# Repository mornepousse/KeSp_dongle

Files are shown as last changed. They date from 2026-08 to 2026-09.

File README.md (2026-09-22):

# KeSp_dongle

USB receiver dongles for the **Niphargus** wireless split keyboard, and soon
for the **Conchodytes** mouse. Both talk 2.4 GHz over nRF24L01+ and share this
single receiver, which presents itself to the host as a USB HID device.

Each Niphargus half is self-contained — its own ESP32-S3-WROOM-1, nRF24L01+ and
16340 cell — and transmits on its own link. Hence the two radios on the dongle,
one per half. The mouse will join on an additional pipe or in a later revision.

KiCad 10 projects. Ecosystem: [Niphargus](https://github.com/mornepousse/Niphargus) (keyboard),
[Conchodytes](https://github.com/mornepousse/Conchodytes) (mouse),
[KeSp_firmware](https://github.com/mornepousse/KeSp_firmware),
[KeSp_software](https://github.com/mornepousse/KeSp_software).

*[Version française plus bas](#version-française).*

| Top | Bottom |
|---|---|
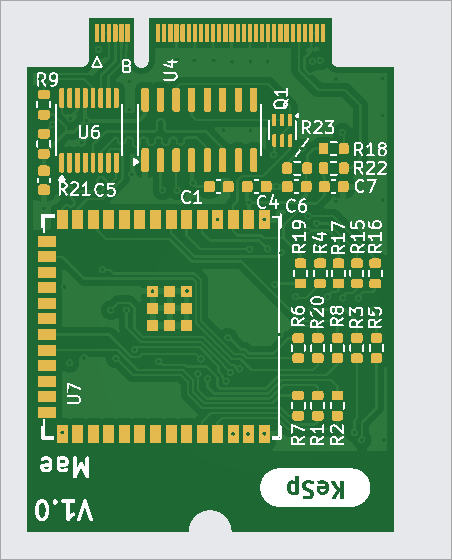
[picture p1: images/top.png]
Board top side
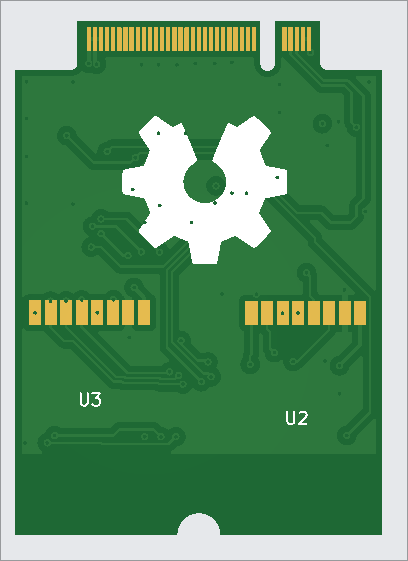
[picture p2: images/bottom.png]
Board bottom side
|  |  |

`dongle-REV1` in revision **V1.0** — the board currently in service.
Top: the CH334R (U6), the CH340C (U4), the ESP32-S3-WROOM-1 (U7) and the M.2
Key B card edge. Bottom: the two NRF24L01+ modules (U2 and U3) on their 2 mm
headers, one per keyboard half.

## The variants

| Folder | MCU | Form factor | Status |
|---|---|---|---|
| `dongle-REV1/` | ESP32-S3-WROOM-1 | M.2 Key B 3042 (30 × 42 mm) | **in service** — V1.0 running in a Dell Latitude 5430's M.2 slot for several months |
| `dongle-REV2/` | ESP32-S3-WROOM-1 | M.2 Key B 3042 (30 × 42 mm) | current design — hub dropped, M.2 CONFIG pins declared, bench supply added; not manufactured yet |
| `dongle-ext/` | ESP32-S3-WROOM-1 | 2.54 mm headers, no M.2 card edge | prototype |

`dongle-REV1` is the only design proven in real use: it enumerates and works as
a USB HID keyboard in the Latitude's M.2 WWAN slot. It does **not** work in a
ThinkPad P16 Gen 1 — the reason, and what REV2 does about it, are written up in
[`docs/hote-thinkpad-p16.md`](docs/hote-thinkpad-p16.md).

## `dongle-REV1` architecture

**Radio** — 2x NRF24L01+ on a shared SPI bus, one per Niphargus half.
Separate CSN/CE/IRQ lines, 100 Ω series resistors on every signal. The
Conchodytes mouse is not wired in yet: it will either share a radio through an
extra receive pipe (the nRF24L01+ handles six) or get its own in a revision.

**USB** — the M.2 slot provides a single USB 2.0 link, split by a hub:

```
M.2 pins 7/9 (D+/D-)
        │
        └─ CH334R (USB 2.0 hub, QSOP-16, crystal-free mode: XI → GND)
             ├── port 1 → ESP32-S3 native USB   (HID in production)
             ├── port 2 → CH340C                (flash and debug without unplugging)
             └── ports 3-4 → unused
```

The CH334R runs natively at 3.3 V with its internal LDO bypassed: **pin 12
(5V) and pin 13 (VDD33) are both tied to 3.3 V**. Leaving pin 12 floating
makes the part overheat and prevents USB enumeration — the classic trap with
this package.

**Power** — no onboard regulator, 3.3 V comes straight from the M.2 slot
(pins 2, 4, 70, 72, 74; grounds on 3, 5, 11, 71, 73).

**M.2 control signals** — `W_DISABLE1#` and `FULL_CARD_POWER_OFF#` get 10 kΩ
pull-ups to 3.3 V, so the host cannot disable the card at boot. `RESET#` is
different: R22 carries it into the ESP32-S3's `EN` node, which also holds a
10 kΩ pull-up (R19) and 100 nF to ground (C7). **The host can therefore reset
the module** — worth remembering when a slot behaves oddly.

| Signal | M.2 pin | Part | Goes to |
|---|---|---|---|
| `W_DISABLE1#` | 8 | R21, 10 kΩ | +3.3 V — pull-up |
| `FULL_CARD_POWER_OFF#` | 6 | R23, 10 kΩ | +3.3 V — pull-up |
| `RESET#` | 67 | R22, 10 kΩ | ESP32-S3 `EN` |

**Auto-reset** — one UMH3N (a dual transistor in SOT-363) driven from the
CH340C DTR/RTS lines to EN and IO0.

## What changed in `dongle-REV2`

REV1 declares nothing on the M.2 CONFIG pins, so a host that reads them before
powering the slot sees "no card present" and never delivers 3.3 V. That is what
happens on a ThinkPad P16 Gen 1. REV2 answers it, and simplifies the USB path
on the way:

| Change | Why |
|---|---|
| `JP2`–`JP5`: CONFIG_0..3 to GND, **open** by default | Lets a code be declared with a solder blob, and swept per host, without a new PCB |
| CH334R hub (`U6`) removed, with `C6` and `J3` | The host now sees a single device whose VID/PID the firmware owns; also retires the CH334R 3.3 V trap |
| ESP32-S3 (`U7:13/14`) straight onto `J2:9/7` | The M.2 USB 2.0 link with nothing in between |
| CH340C (`U4`) moved to `J1` (1 GND, 2 D−, 3 D+, 4 VBUS) | Serial console and auto-reset kept, as a bench programming port |
| `U1` LD1117S33 + `C13`/`C14`, preceded by `D1` (SS14) | Runs the board from the bench cable's VBUS. The series Schottky blocks the slot's 3.3 V from feeding back to the connector through the regulator's internal parasitic path |
| `JP6` between the LDO output and the `+3.3V` rail, **open** by default | Stops the LDO from powering the laptop's WWAN rail when the bench cable is plugged with the card inserted. `C13` stays on the LDO side, so the regulator keeps its output capacitor with the jumper open |

Flashing without unplugging used to go through the CH340C behind the hub. It
now goes through the ESP32-S3's own USB Serial/JTAG over the M.2 link: its
CDC-ACM "supports host controllable chip reset and entry into download mode"
(ESP32-S3 TRM v1.8, p. 1244). Note that the internal USB PHY is **shared**
between USB-OTG and USB Serial/JTAG, one at a time (p. 1244-1245): while the
firmware holds the PHY in OTG for HID, the serial console is gone.

Checked with `kicad-cli` on 2026-09-22: **0 schematic/PCB parity issues, 0
unconnected items**, 41 components on each side.

## Libraries

Custom footprints live in `libs/` and are referenced as
`${KIPRJMOD}/../libs/…` by each project's `fp-lib-table` — no absolute paths,
so the repository clones anywhere.

| Library | Contents |
|---|---|
| `libs/MaeLid.pretty` | NRF24L01, ESP32-S3-DevKitC, JC-ESP32P4-M3, logo |
| `libs/M.2-cards` | M.2 card outline templates |
| `libs/NGFF.pretty` | M.2 / NGFF connectors |

Everything else comes from the standard KiCad libraries and from
`PCM_Espressif` (Plugin and Content Manager, install separately).

## Open items

- `dongle-REV2`: **no clearance exception on `J2`**. 58 of the DRC's 102
  violations are simply adjacent M.2 gold fingers at 0.150 mm against a
  0.200 mm rule. Until an exception is set, the DRC is red by default and
  stops being useful.
- `dongle-REV2`: leftovers to clean — two real clearance violations (`C9` pad
  vs the `/IO0` via at 0.175 mm, GND copper vs `J2:9` at 0.150 mm), a dangling
  via on the VBUS net, a 14 µm dangling track on `/D-_ESP32`, and two
  single-spoke thermal reliefs (`C13`, `J1`).
- `dongle-REV2`: `C8` through `C14` carry `Resistor_SMD:R_1206_3216Metric`.
  Same land pattern, but the BOM and JLCPCB files will describe a resistor
  footprint for 10 µF capacitors. `C14` at 10 µF also sits exactly on the bulk
  capacitance a USB 2.0 device may present on VBUS.
- `dongle-REV2`: `J1` is wired 1 = GND, 2 = D−, 3 = D+, 4 = VBUS, the reverse
  of a USB-A cable's order. The pigtail must be built to match.
- Whether the P16 Gen 1 powers its WWAN slot at all, and on which CONFIG code,
  is still unmeasured. The test costs a wire on an existing V1.0 board — see
  [`docs/hote-thinkpad-p16.md`](docs/hote-thinkpad-p16.md).

## Fabrication

| Folder | Output | Exported |
|---|---|---|
| `dongle-REV1/Gerber/` | gerbers of the manufactured V1.0 batch | 2026-05-27 |
| `dongle-REV1/jlcpcb/` | JLCPCB set — gerbers, BOM, CPL | 2026-08-22 |
| `dongle-REV2/jlcpcb/` | JLCPCB set — gerbers, BOM, CPL | 2026-09-22, after `JP6` |
| `dongle-ext/Gerber/` | gerbers | 2026-06-04 |

REV2's export is in sync with its source, but none of the open items above are
fixed in it — the dangling via and track, the two real clearance violations.
Clean those before ordering.

The REV1 gerbers match the batch that was manufactured, revision V1.0. That
source has since moved on: R9 removed, decoupling completed (C8 through C12),
and the `JP2`–`JP5` CONFIG jumpers added — so `dongle-REV1/` no longer
describes the board sitting in the Latitude.

Neither exported netlists (`*.net`) nor fabrication archives (`*.zip`) are
version-controlled: both regenerate from the source, and importing a stale
netlist overwrites current work.

## Documentation

- [`docs/hote-thinkpad-p16.md`](docs/hote-thinkpad-p16.md) — why the M.2 WWAN
  slot of a ThinkPad P16 Gen 1 never powers the card, the M.2 CONFIG pins, what
  other USB cards in M.2 slots do, the test protocol, and REV2's state.

---

# Version française

Dongles USB récepteurs pour le clavier split sans fil **Niphargus**, et
bientôt pour la souris **Conchodytes**. Les deux émettent en 2,4 GHz via un
nRF24L01+ et partagent ce même récepteur, qui se présente au PC en USB HID.

Chaque moitié du Niphargus est autonome — son ESP32-S3-WROOM-1, son nRF24L01+
et sa cellule 16340 — et émet sur son propre lien. D'où les deux radios du
dongle, une par moitié. La souris arrivera sur un pipe supplémentaire ou dans
une révision ultérieure.

Projets KiCad 10. Écosystème : [Niphargus](https://github.com/mornepousse/Niphargus) (clavier),
[Conchodytes](https://github.com/mornepousse/Conchodytes) (souris),
[KeSp_firmware](https://github.com/mornepousse/KeSp_firmware),
[KeSp_software](https://github.com/mornepousse/KeSp_software).

Les rendus plus haut montrent `dongle-REV1` en révision **V1.0**, la carte
actuellement en service. Dessus : le CH334R (U6), le CH340C (U4),
l'ESP32-S3-WROOM-1 (U7) et le bord de carte M.2 Key B. Dessous : les deux
NRF24L01+ (U2 et U3) sur leurs embases 2 mm, un par moitié de clavier.

## Les variantes

| Dossier | MCU | Format | État |
|---|---|---|---|
| `dongle-REV1/` | ESP32-S3-WROOM-1 | M.2 Key B 3042 (30 × 42 mm) | **en service** — V1.0 montée dans le slot M.2 d'un Dell Latitude 5430 depuis plusieurs mois |
| `dongle-REV2/` | ESP32-S3-WROOM-1 | M.2 Key B 3042 (30 × 42 mm) | conception courante — hub supprimé, pins CONFIG déclarées, alimentation de banc ajoutée ; pas encore fabriquée |
| `dongle-ext/` | ESP32-S3-WROOM-1 | connecteurs 2,54 mm, pas de bord M.2 | prototype |

`dongle-REV1` est la seule éprouvée à l'usage : elle énumère et fonctionne en
clavier USB HID dans le slot M.2 WWAN du Latitude. Elle **ne fonctionne pas**
dans un ThinkPad P16 Gen 1 — la raison, et ce que REV2 y répond, sont
consignées dans [`docs/hote-thinkpad-p16.md`](docs/hote-thinkpad-p16.md).

## Architecture de `dongle-REV1`

**Radio** — 2x NRF24L01+ sur bus SPI partagé, un par moitié de Niphargus.
CSN/CE/IRQ séparés, résistances série de 100 Ω sur chaque signal. La souris
Conchodytes n'est pas encore câblée : elle partagera une radio via un pipe de
réception supplémentaire (le nRF24L01+ en gère six) ou aura la sienne dans une
révision.

**USB** — le slot M.2 fournit un seul lien USB 2.0, dédoublé par un hub :

```
M.2 pins 7/9 (D+/D-)
        │
        └─ CH334R (hub USB 2.0, QSOP-16, mode sans quartz : XI → GND)
             ├── port 1 → USB natif de l'ESP32-S3   (HID en production)
             ├── port 2 → CH340C                    (flash et debug sans démonter)
             └── ports 3-4 → non utilisés
```

Le CH334R tourne en 3,3 V natif, LDO interne bypassé : **pin 12 (5V) et
pin 13 (VDD33) toutes deux au 3,3 V**. Laisser la pin 12 flottante fait
chauffer le composant et empêche l'énumération — c'est le piège de ce boîtier.

**Alimentation** — aucun régulateur embarqué, le 3,3 V vient directement du
slot M.2 (pins 2, 4, 70, 72, 74 ; masses sur 3, 5, 11, 71, 73).

**Signaux M.2** — `W_DISABLE1#` et `FULL_CARD_POWER_OFF#` reçoivent des
pull-ups de 10 kΩ vers 3,3 V, pour que la carte ne soit pas désactivée au
démarrage. `RESET#` est différent : R22 l'amène sur le nœud `EN` de
l'ESP32-S3, qui porte aussi un pull-up de 10 kΩ (R19) et 100 nF vers la masse
(C7). **L'hôte peut donc réinitialiser le module** — bon à savoir quand un slot
se comporte bizarrement.

| Signal | Pin M.2 | Composant | Va vers |
|---|---|---|---|
| `W_DISABLE1#` | 8 | R21, 10 kΩ | +3,3 V — pull-up |
| `FULL_CARD_POWER_OFF#` | 6 | R23, 10 kΩ | +3,3 V — pull-up |
| `RESET#` | 67 | R22, 10 kΩ | `EN` de l'ESP32-S3 |

**Reset automatique** — un UMH3N (double transistor en SOT-363) piloté par les
lignes DTR/RTS du CH340C vers EN et IO0.

## Ce qui change dans `dongle-REV2`

REV1 ne déclare rien sur les pins CONFIG du M.2 : un hôte qui les lit avant
d'alimenter le slot comprend « pas de carte » et ne délivre jamais le 3,3 V.
C'est ce qui se passe sur un ThinkPad P16 Gen 1. REV2 y répond, et simplifie le
chemin USB au passage :

| Modification | Raison |
|---|---|
| `JP2`–`JP5` : CONFIG_0..3 vers GND, **ouverts** par défaut | Permet de déclarer un code à la goutte de soudure, et de les balayer selon l'hôte, sans refaire un PCB |
| Hub CH334R (`U6`) supprimé, avec `C6` et `J3` | L'hôte ne voit plus qu'un périphérique, dont le firmware maîtrise le VID/PID ; supprime aussi le piège du 3,3 V du CH334R |
| ESP32-S3 (`U7:13/14`) directement sur `J2:9/7` | Le lien USB 2.0 du M.2 sans rien entre les deux |
| CH340C (`U4`) déplacé sur `J1` (1 GND, 2 D−, 3 D+, 4 VBUS) | Console série et auto-reset conservés, en port de programmation de banc |
| `U1` LD1117S33 + `C13`/`C14`, précédé de `D1` (SS14) | Alimente la carte depuis le VBUS du câble de banc. Le Schottky en série bloque le retour du 3,3 V du slot vers le connecteur par le parasite interne du régulateur |
| `JP6` entre la sortie du LDO et le rail `+3.3V`, **ouvert** par défaut | Empêche le LDO d'alimenter le rail WWAN du portable si le câble de banc est branché carte insérée. `C13` reste côté LDO, qui garde donc sa capacité de sortie jumper ouvert |

Le « flash sans démonter » que permettait le CH340C derrière le hub passe
désormais par l'USB Serial/JTAG de l'ESP32-S3 sur la liaison M.2 : son CDC-ACM
« supports host controllable chip reset and entry into download mode »
(ESP32-S3 TRM v1.8, p. 1244). À noter que le PHY USB interne est **partagé**
entre l'USB-OTG et l'USB Serial/JTAG, un seul à la fois (p. 1244-1245) : tant
que le firmware tient le PHY en OTG pour le HID, la console série disparaît.

Vérifié au `kicad-cli` le 22/09/2026 : **0 problème de parité schéma/PCB, 0
élément non connecté**, 41 composants de chaque côté.

## Bibliothèques

Les empreintes maison vivent dans `libs/` et sont référencées en
`${KIPRJMOD}/../libs/…` par le `fp-lib-table` de chaque projet — aucun chemin
absolu, le dépôt se clone n'importe où.

| Lib | Contenu |
|---|---|
| `libs/MaeLid.pretty` | NRF24L01, ESP32-S3-DevKitC, JC-ESP32P4-M3, logo |
| `libs/M.2-cards` | gabarits de cartes M.2 |
| `libs/NGFF.pretty` | connecteurs M.2 / NGFF |

Le reste vient des bibliothèques standard KiCad et de `PCM_Espressif`
(gestionnaire de contenu, à installer séparément).

## Points ouverts

- `dongle-REV2` : **aucune exception d'isolation posée sur `J2`**. 58 des 102
  violations du DRC ne sont que des doigts dorés M.2 voisins, à 0,150 mm contre
  une règle à 0,200 mm. Tant que l'exception n'est pas posée, le DRC est rouge
  par construction et cesse d'être utile.
- `dongle-REV2` : restes à nettoyer — deux isolations réelles (pad de `C9`
  contre la via `/IO0` à 0,175 mm, cuivre GND contre `J2:9` à 0,150 mm), une
  via orpheline sur le net VBUS, une piste orpheline de 14 µm sur `/D-_ESP32`,
  et deux freins thermiques à un seul rayon (`C13`, `J1`).
- `dongle-REV2` : `C8` à `C14` portent `Resistor_SMD:R_1206_3216Metric`. Même
  pastille, mais la BOM et les fichiers JLCPCB décriront une empreinte de
  résistance pour des condensateurs de 10 µF. `C14` à 10 µF est par ailleurs
  exactement à la capacité de bulk maximale qu'un périphérique USB 2.0 peut
  présenter sur VBUS.
- `dongle-REV2` : `J1` est câblé 1 = GND, 2 = D−, 3 = D+, 4 = VBUS, soit
  l'inverse de l'ordre d'un câble USB-A. Le pigtail doit être fait en
  conséquence.
- Savoir si le P16 Gen 1 alimente son slot WWAN, et sur quel code CONFIG, n'est
  toujours pas mesuré. L'essai coûte un fil sur une V1.0 existante — voir
  [`docs/hote-thinkpad-p16.md`](docs/hote-thinkpad-p16.md).

## Fabrication

| Dossier | Sortie | Exporté le |
|---|---|---|
| `dongle-REV1/Gerber/` | gerbers de la série V1.0 fabriquée | 27/05/2026 |
| `dongle-REV1/jlcpcb/` | jeu JLCPCB — gerbers, BOM, CPL | 22/08/2026 |
| `dongle-REV2/jlcpcb/` | jeu JLCPCB — gerbers, BOM, CPL | 22/09/2026, après `JP6` |
| `dongle-ext/Gerber/` | gerbers | 04/06/2026 |

L'export de REV2 est à jour vis-à-vis de sa source, mais aucun des points
ouverts ci-dessus n'y est corrigé — la via et la piste orphelines, les deux
isolations réelles. À nettoyer avant toute commande.

Les gerbers de REV1 correspondent à la série reçue, en révision V1.0. Cette
source a depuis évolué : R9 supprimée, découplage complété (C8 à C12), et
jumpers CONFIG `JP2`–`JP5` ajoutés — `dongle-REV1/` ne décrit donc plus la
carte montée dans le Latitude.

Ni les netlists exportées (`*.net`) ni les archives de fabrication (`*.zip`) ne
sont versionnées : les deux se régénèrent depuis la source, et importer une
netlist périmée écrase le travail en cours.

## Documentation

- [`docs/hote-thinkpad-p16.md`](docs/hote-thinkpad-p16.md) — pourquoi le slot
  M.2 WWAN d'un ThinkPad P16 Gen 1 n'alimente jamais la carte, les pins CONFIG
  du M.2, ce que font les autres cartes USB en slot M.2, le protocole d'essai,
  et l'état de REV2.

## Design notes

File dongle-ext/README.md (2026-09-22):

# dongle-ext — header prototype, no M.2

USB HID receiver for the **Niphargus** split keyboard, in the same shape as the
M.2 variants but without the card edge: USB arrives on a 2.54 mm header, and
the board carries its own regulator.

Prototype, kept for bench work and for hosts with no usable M.2 slot. The
designs that go in a laptop are [`../dongle-REV1/`](../dongle-REV1/) and
[`../dongle-REV2/`](../dongle-REV2/).

## Architecture

```
J1, 4-pin 2.54 mm header
  ├── VBUS 5 V ──> U1 (LD1117S33) ──> 3.3 V rail
  └── D+/D− ────> CH334R hub ──┬─> port 1: ESP32-S3 native USB (HID)
                               ├─> port 2: CH340C (UART, flash/debug)
                               └─> ports 3-4: not connected

ESP32-S3 ──SPI──┬── NRF24L01+ U2 ──2.4 GHz── Niphargus left half
                └── NRF24L01+ U3 ──2.4 GHz── Niphargus right half
```

## J1

| Pin | Signal |
|---|---|
| 1 | GND |
| 2 | USB D− |
| 3 | USB D+ |
| 4 | VBUS, 5 V |

**This is the reverse of a USB-A cable's pin order.** Build the pigtail to
match, or 5 V lands on ground.

## Components

| Ref | Part | Role | Package |
|---|---|---|---|
| U7 | ESP32-S3-WROOM-1 | MCU, USB HID | module |
| U2, U3 | NRF24L01+ | one radio per keyboard half | breakout, 2 mm headers |
| U6 | CH334R | USB 2.0 hub, crystal-free | QSOP-16 |
| U4 | CH340C | USB-to-UART for flashing and console | SOIC-16 |
| U1 | LD1117S33 | 3.3 V from J1's VBUS | SOT-223 |
| Q1 | UMH3N | auto-reset, DTR/RTS to EN and IO0 | SOT-363 |

Q1 is a **dual** transistor: its two schematic units are one physical package.

## Differences from the M.2 variants

- **Own supply**: LD1117S33 from the header's 5 V, instead of the slot's 3.3 V.
  There is no reverse-blocking diode here — nothing can back-feed the header,
  since there is no second source.
- **R9 is still fitted**: 100 Ω between the 3.3 V rail and the CH334R's pin 12
  (5V). REV1 dropped it in V1.1 and ties pin 12 straight to 3.3 V. Either way
  the point stands — leave pin 12 floating and the part overheats and refuses
  to enumerate.
- **No M.2 control signals**: no CONFIG pins, no `W_DISABLE1#`, no `RESET#`
  into `EN`. The host cannot reset the module.

## PCB

KiCad 10. Gerbers in `Gerber/`, exported 2026-06-04.

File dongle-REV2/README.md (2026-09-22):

# dongle-REV2 — M.2 Key B receiver, no hub

USB HID receiver for the **Niphargus** split keyboard: two NRF24L01+ radios,
one per half, an ESP32-S3-WROOM-1, and an M.2 Key B card edge that plugs into a
laptop WWAN slot.

Current design, **not manufactured yet**. It starts from
[`../dongle-REV1/`](../dongle-REV1/) and answers the ThinkPad P16 Gen 1, whose
WWAN slot never powers the V1.0 board. The full story, with the measurements
still to make, is in [`../docs/hote-thinkpad-p16.md`](../docs/hote-thinkpad-p16.md).

## What changed from REV1

| Change | Why |
|---|---|
| `JP2`–`JP5`: CONFIG_0..3 to GND, **open** by default | REV1 leaves the CONFIG pins floating, so a host that reads them before powering the slot sees "no add-in card present". A solder blob now declares a code, and the codes can be swept per host without a new PCB |
| CH334R hub (U6) removed, with C6 and J3 | The host sees a single device whose VID/PID the firmware owns; also retires the CH334R 3.3 V trap |
| ESP32-S3 straight onto M.2 pins 7/9 | The USB 2.0 link with nothing in between |
| CH340C moved to J1 | Serial console and auto-reset kept, as a bench programming port |
| U1 (LD1117S33) behind D1 (SS14), with C13/C14 | Runs the board from J1's VBUS. The series Schottky blocks the slot's 3.3 V from feeding back to the connector through the regulator's parasitic path |
| `JP6`, **open** by default | Isolates the LDO output from the 3.3 V rail, so the card cannot power the laptop's WWAN rail with the bench cable plugged in |

## Architecture

```
M.2 WWAN slot
  ├── USB 2.0, pins 7/9 ───────> ESP32-S3 native USB (HID), no hub
  ├── 3.3 V, pins 2/4/70/72/74 ─> main rail
  └── RESET#, pin 67 ──R22 10k─> ESP32-S3 EN

J1, bench port ── VBUS ──> D1 (SS14) ──> U1 (LD1117S33) ──JP6──> 3.3 V rail
                └─ D+/D− ──> CH340C ──UART──> ESP32-S3

ESP32-S3 ──SPI──┬── NRF24L01+ U2 ──2.4 GHz── Niphargus left half
                └── NRF24L01+ U3 ──2.4 GHz── Niphargus right half
```

Only one of the two supplies should be live at a time. `JP6` open is the
default; close it only when running off the bench cable with the card out of
the slot.

## M.2 Key B connections

| M.2 pin | Signal | On this board |
|---|---|---|
| 1, 21, 69, 75 | CONFIG_3, _0, _1, _2 | JP5, JP2, JP3, JP4 — solder jumpers to GND, **open by default** |
| 2, 4, 70, 72, 74 | +3.3 V | main rail |
| 3, 5, 11, 27, 33, 39, 45, 51, 57, 71, 73 | GND | ground |
| 6 | `FULL_CARD_POWER_OFF#` | R23, 10 kΩ pull-up to 3.3 V |
| 7 | `USB_D+` | ESP32-S3 GPIO20 (U7:14) |
| 8 | `W_DISABLE1#` | R21, 10 kΩ pull-up to 3.3 V |
| 9 | `USB_D−` | ESP32-S3 GPIO19 (U7:13) |
| 67 | `RESET#` | R22, 10 kΩ into the ESP32-S3 `EN` node |
| everything else | — | not connected |

`EN` also carries a 10 kΩ pull-up (R19) and 100 nF to ground (C7), so the host
can reset the module through pin 67.

## J1 — bench port

| Pin | Signal |
|---|---|
| 1 | GND |
| 2 | USB D− |
| 3 | USB D+ |
| 4 | VBUS, 5 V |

**This is the reverse of a USB-A cable's pin order.** Build the pigtail to
match, or 5 V lands on ground.

## Components

| Ref | Part | Role | Package |
|---|---|---|---|
| U7 | ESP32-S3-WROOM-1 | MCU, USB HID, native USB on the M.2 link | module |
| U2, U3 | NRF24L01+ | one radio per keyboard half | breakout, 2 mm headers |
| U4 | CH340C | USB-to-UART on the bench port | SOIC-16 |
| U1 | LD1117S33 | 3.3 V from J1's VBUS | SOT-223 |
| D1 | SS14 | 40 V / 1 A Schottky, blocks reverse current into J1 | SMA |
| Q1 | UMH3N | auto-reset, DTR/RTS to EN and IO0 | SOT-363 |
| JP2–JP5 | — | M.2 CONFIG code | solder jumpers |
| JP6 | — | LDO output isolation | solder jumper |

Q1 is a **dual** transistor: its two schematic units are one physical package.

## Flashing

In the slot, through the ESP32-S3's own USB Serial/JTAG on the M.2 link — its
CDC-ACM "supports host controllable chip reset and entry into download mode"
(ESP32-S3 TRM v1.8, p. 1244). Note that the internal USB PHY is **shared**
between USB-OTG and USB Serial/JTAG, one at a time (p. 1244-1245): while the
firmware holds the PHY in OTG for HID, that console is gone.

On the bench, through J1 and the CH340C, which keeps a real UART console
whatever the PHY is doing.

## PCB

M.2 Key B **3042 (30 × 42 mm)**, 0.8 mm thick, 4 layers. KiCad 10. Production
files in `jlcpcb/`; there is deliberately no `Gerber/` folder, so no stale V1.0
export can be sent to a fab by mistake.

Checked with `kicad-cli` on 2026-09-22: 0 schematic/PCB parity issues, 0
unconnected items. Known leftovers are listed in the repository's
[`../README.md`](../README.md) — a dangling via and track, two real clearance
violations, and no clearance exception on J2 yet.

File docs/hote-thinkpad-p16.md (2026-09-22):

# Hôte ThinkPad P16 Gen 1 — le slot WWAN n'alimente pas la V1.0

Constaté le 2026-09-17 sur un ThinkPad P16 Gen 1 `21D60019FR` (Alder Lake HX,
BIOS N3FET46W 1.70, SKU sans module WWAN **mais avec les 4 antennes**).

Mis à jour le 2026-09-22 : retours publics rassemblés, correction de ce qui
était écrit ici sur la whitelist, et état de la carte `dongle-REV2`.

## Symptôme

La carte `dongle-REV1` en V1.0 — l'ancien `dongle-s3` —, qui fonctionne dans le
slot WWAN d'un Dell Latitude 5430, **n'apparaît nulle part** sur le P16 : aucune
tentative d'énumération USB dans `dmesg`, aucun `rfkill` WWAN, aucune option
« Wireless WAN » au BIOS. Autrement dit le slot n'est jamais mis sous tension.

## Cause : les pins CONFIG[3:0]

La spec M.2 fait lire à l'hôte quatre broches de configuration **avant**
d'alimenter la carte, pour savoir ce qui est inséré :

> *The system shall read all four configuration pins to identify the selected
> pinout configuration. The system shall pull-up these configuration pins to an
> appropriate power rail so the configuration pins can be read even if the M.2
> expansion card is not powered.*
> — congatec AN43, « M.2 Pinout Descriptions and Reference Designs », p. 9

C'est donc **l'hôte qui fournit les pull-ups** ; la carte se contente de tirer
à la masse ce qu'elle veut déclarer. `0` = relié à GND sur la carte, `1` =
laissé en l'air.

| CONFIG_0 (21) | CONFIG_1 (69) | CONFIG_2 (75) | CONFIG_3 (1) | Interface déclarée |
|---|---|---|---|---|
| 0 | 0 | 0 | 0 | SSD SATA |
| 0 | 1 | 0 | 0 | SSD PCIe |
| 0 | 0 | 1 | 0 | WWAN PCIe (port cfg 0) |
| 0 | 0 | 0 | 1 | WWAN PCIe + USB3.1 Gen1 (port cfg 0) |
| 1 | 0 | 0 | 0 | WWAN SSIC (port cfg 0) |
| **1** | **1** | **1** | **1** | **No Add-in Card Present** |

Sur la V1.0, **les quatre broches sont flottantes** → l'hôte lit `1111`,
comprend « pas de carte », et l'EC ne délivre jamais le 3,3 V. Le Dell 5430
alimentait le slot sans lire CONFIG : c'est lui qui était laxiste, pas le
Lenovo qui est cassé. La carte est simplement non conforme sur ce point.

## Ce que font les autres cartes USB en slot M.2

L'omission n'est pas propre à cette carte. **`timonsku/RP2040-M.2`**, la
référence open source d'une carte M.2 B-key purement USB 2.0, câble 30 pins sur
75 et **laisse ses quatre CONFIG en l'air** — vérifié en cartographiant son
schéma : pins 1, 21, 69 et 75 non connectées, `RESET#` (67) non plus, seuls
`FULL_CARD_POWER_OFF#` et `W_DISABLE1#` sont repris. Elle déclare donc `1111`
elle aussi. Tout le monde teste sur des hôtes laxistes, et personne n'a eu à
résoudre le cas strict : d'où l'absence de documentation sur le sujet.

La catégorie existe pourtant en produit fini : des cartes M.2 Key B qui vivent
dans le slot WWAN et y présentent un périphérique USB — lecteurs microSD, et
des adaptateurs dont la notice liste explicitement « USB wireless cards, **USB
mouse receivers**, USB SSDs », avec une limite de 28 mm de long.

Côté ThinkPad précisément, le modem Sierra EM7455 « is connected internally by
USB in ThinkPad devices » : ces machines câblent et énumèrent bien l'USB 2.0 de
leur slot WWAN. Et la série M.2 de Hackaday résume la situation des slots B :
« *you can only really rely on USB 2.0 being present – everything else highly
varies* ». Le seul bus fiable dans un slot B est précisément celui dont cette
carte a besoin.

**Ce qu'on n'a pas trouvé** : aucun retour portant sur un P16 Gen 1, et aucun
cas documenté d'un Lenovo refusant d'alimenter une carte à cause de
`CONFIG = 1111`. L'hypothèse de ce document est la meilleure explication
disponible, cohérente avec tout ce qui précède, mais elle n'est corroborée par
aucun témoignage direct.

## Les deux verrous, et leur poids réel

### 1. L'alimentation du slot — le vrai obstacle

C'est ici que tout se joue, et la recherche l'a plutôt durci. La carte que le
P16 accepte, la Fibocom L860-GL, a pour interface de données le **PCIe Gen2**,
l'USB2 n'y servant qu'au debug. Le slot du P16 est donc provisionné pour du
PCIe. Que les paires USB 2.0 des pins 7/9 soient effectivement câblées reste
probable — elles appartiennent au brochage Key B WWAN et la L860 s'en sert —
mais ce n'est pas démontré sur ce modèle.

Reste une question que nulle datasheet ne tranche : si le BIOS lit un code
CONFIG WWAN, cherche un périphérique PCIe et n'en trouve aucun, laisse-t-il le
rail 3,3 V debout ?

### 2. La whitelist 1802 — moins menaçante qu'annoncé

**Correction de ce qui était écrit ici.** Le contrôle 1802 vérifie le
**sub-vendor PCI-ID** de la carte, et pour le WWAN il exige en plus un numéro
FRU Lenovo listé. Il mord donc sur un identifiant **PCI**. Une carte purement
USB n'a pas de PCI-ID du tout : elle n'existe pas dans l'espace de configuration
PCI, et le test n'a rien à mordre.

C'est cohérent avec le fait que des modems USB fonctionnent dans ces slots :
quand un EM7455 se fait refuser, c'est par son PCI-ID de sous-système, pas
parce qu'il est USB.

Ce verrou-là n'est donc probablement pas celui qui bloque. À noter tout de
même : **aucun BIOS modifié n'est possible** sur cette machine — Alder Lake
avec Intel Boot Guard, clés fusées dans le CPU. Les contournements des vieux
ThinkPad n'ont pas d'équivalent, même en flashant la puce SPI au clip.

Et rappel utile : **changer le VID/PID de l'ESP32-S3 ne sert à rien tant que le
slot n'est pas alimenté**. Sans 3,3 V il n'y a aucun descripteur USB à
présenter.

## Protocole d'essai, sur une V1.0 existante

Rien de tout ceci ne justifie un nouveau PCB avant d'avoir mesuré. Les pins
CONFIG sont des doigts dorés accessibles : un fil fin entre la pin à déclarer et
une masse voisine (3, 5 ou 11) suffit à poser un code sur une carte déjà en
main. Une soirée, zéro fab.

1. Multimètre, carte retirée, machine sous tension : vérifier ~3,3 V (ou 1,8 V)
   sur les pins 21, 69, 75, 1 du slot → confirme que l'hôte lit bien CONFIG.
2. Poser un code WWAN au fil (ex. `0 0 0 1` : 21, 69, 75 à la masse, 1
   flottante), puis balayer les autres codes WWAN du tableau.
3. Vérifier l'alimentation du slot, puis `lsusb | grep 303a`.
4. Un `1802` au POST n'est pas un échec total : il prouve que le slot est
   alimenté et que le BIOS voit la carte. Bloquant mais réversible — retirer
   la carte suffit.

Si le slot reste mort quel que soit le code, aucun respin n'y changera rien et
c'est le repli FFC ci-dessous qui devient la réponse.

## État de la carte REV2

`dongle-REV2` intègre les conclusions ci-dessus. Par rapport à REV1 :

| Modification | Raison |
|---|---|
| `JP2`–`JP5` : CONFIG_0..3 vers GND, **ouverts** par défaut | Permet de balayer les codes selon l'hôte sans refaire un PCB. Coût nul en BOM. |
| Hub CH334R (`U6`) supprimé, avec `C6` et `J3` | L'hôte ne voit plus qu'un périphérique, dont le firmware maîtrise le VID/PID. Supprime aussi le piège du 3,3 V natif de ce boîtier. |
| ESP32-S3 (`U7:13/14`) directement sur `J2:9/7` | USB 2.0 du M.2 attaqué sans intermédiaire. |
| CH340C (`U4`) déplacé sur `J1` (1 GND, 2 D−, 3 D+, 4 VBUS) | Console série et auto-reset conservés, en port de programmation de banc. |
| `U1` LD1117S33 + `C13`/`C14`, précédé de `D1` (SS14) | Alimente la carte depuis le VBUS du câble de banc. Le SS14 en série bloque le retour du 3,3 V du slot vers le connecteur par le parasite interne du régulateur. |
| `JP6` entre la sortie du LDO et le rail `+3.3V`, **ouvert** par défaut | Empêche le LDO d'alimenter le rail WWAN du portable si le câble de banc est branché carte insérée — ce qui fausserait la mesure de l'étape 1 ci-dessus. `C13` reste côté LDO, qui garde sa capacité de sortie jumper ouvert. |

Le `flash sans démonter` que permettait le CH340C derrière le hub passe
désormais par l'USB Serial/JTAG de l'ESP32-S3 sur la liaison M.2 : son CDC-ACM
« supports host controllable chip reset and entry into download mode »
(ESP32-S3 TRM v1.8, p. 1244). À noter que le PHY USB interne est **partagé**
entre l'USB-OTG et l'USB Serial/JTAG, un seul à la fois (p. 1244-1245) : quand
le firmware tient le PHY en OTG pour le HID, la console série disparaît.

### Vérification au 2026-09-22

`kicad-cli`, schéma et PCB : **0 problème de parité, 0 élément non connecté**,
41 composants de chaque côté.

- **ERC — 54 violations** : 51 sur les pins inutilisées du connecteur M.2
  (PCIe, SATA, SIM/UIM, USB 3.0), bruit normal. Restent le MISO partagé entre
  les deux nRF24 (faux positif, bus SPI) et deux `PWR_FLAG` manquants.
- **DRC — 102 violations**, dont **58 entre pads voisins du connecteur M.2
  lui-même**, toutes à 0,150 mm contre une règle à 0,200 mm : c'est le pas
  normalisé des doigts dorés, pas un défaut. Sans exception d'isolation posée
  sur `J2`, le DRC reste rouge en permanence et cesse d'être utile.
- Reste à nettoyer : 2 isolations réelles (`C9`/via `/IO0` à 0,175 mm, cuivre
  GND contre `J2:9` à 0,150 mm), une via orpheline sur le net VBUS, une piste
  orpheline de 14 µm sur `/D-_ESP32`, deux freins thermiques à un seul rayon
  (`C13`, `J1`), `J2` dans une zone interdite, et la sérigraphie.

### Points connus, non bloquants

- `C8` à `C14` portent `Resistor_SMD:R_1206_3216Metric` : même pastille, mais la
  BOM et les fichiers JLCPCB décriront une empreinte de résistance pour des
  condensateurs de 10 µF.
- `C14` est à 10 µF sur VBUS, exactement la limite admise côté périphérique par
  l'USB 2.0 ; 4,7 µF serait plus sûr à la connexion à chaud.
- Budget de tension du chemin de banc : `VBUS − 0,3 V (D1) − ~1 V (dropout du
  LD1117)`, soit 3,7 V depuis un VBUS à 5 V — confortable. Depuis un VBUS
  affaissé à 4,4 V en bout de câble il ne reste que 3,1 V et la régulation
  décroche. Une diode supplémentaire en sortie du LDO rendrait ce budget
  intenable : c'est pourquoi l'isolation de sortie est un jumper, pas une diode.
- `J1` est câblé 1 = GND, 2 = D−, 3 = D+, 4 = VBUS, soit l'inverse de l'ordre
  d'un câble USB-A. Le pigtail doit être fait en conséquence.
- Les deux symboles `Q1` sont les **unités 1 et 2 d'un même UMH3N** — un double
  transistor en SOT-363. Une seule empreinte au PCB est correcte ; le point
  ouvert du README qui demande de réannoter en Q1/Q2 est erroné.

## Repli garanti, sans slot M.2

L'USB interne du **lecteur de carte à puce** (`2ce3:9563` sur le P16, inutilisé
ici) : connecteur carte mère n° 11 « Smart card reader connector » + nappe FFC
(FRU n° 28), dépose au § 1180 de la HMM P16 Gen 1 — après la base (§ 1070) et
le bezel clavier (§ 1150). Le lecteur tient par 2 vis M2×3,5 au bord avant
gauche, dans un logement de la taille d'un 2242. Relever VBUS / GND / D+ / D−
sur la nappe et les amener à l'entrée USB de la carte : aucune whitelist, aucun
CONFIG, alimentation garantie.

D'où une idée pour une révision ultérieure : prévoir un **connecteur FFC en
entrée USB alternative**, ce qui rendrait la carte utilisable sur n'importe quel
portable ayant un lecteur de carte à puce, indépendamment du slot M.2. La place
libérée par le CH334R en REV2 y suffirait, si le LD1117 en SOT-223 n'en
occupait pas déjà l'essentiel.

## Côté hôte NixOS

Les règles udev de `mae` épinglent `303a:4001` (`modules/hardware/kase-dongle.nix` :
accès hidraw non-root, symlink `/dev/ttyKASE_DONGLE`). Si le VID/PID du firmware
change un jour, ce fichier doit être mis à jour en même temps.

## Sources

- congatec AN43, *M.2 Pinout Descriptions and Reference Designs*, p. 9 (table CONFIG) —
  `https://www.congatec.com/fileadmin/user_upload/Documents/Application_Notes/AN43_M.2_Pinout_Descriptions_and_Reference_Designs.pdf`
- Espressif, *ESP32-S3 Technical Reference Manual* v1.8, p. 1244-1245 (PHY USB
  partagé, reset et download mode par CDC-ACM)
- STMicroelectronics, *LD1117 datasheet* (dropout 1 V typ., Id 5 mA typ. /
  10 mA max) — `https://www.st.com/resource/en/datasheet/ld1117.pdf`
- `timonsku/RP2040-M.2`, carte M.2 B-key USB 2.0 open source —
  `https://github.com/timonsku/RP2040-M.2`
- Hackaday, *M.2 For Hackers – Expand Your Laptop* —
  `https://hackaday.com/2022/10/27/m-2-for-hackers-expand-your-laptop/`
- `danielewood/sierra-wireless-modems` (EM7455 relié en USB interne sur ThinkPad) —
  `https://github.com/danielewood/sierra-wireless-modems`
- Fibocom, *L860-GL Hardware User Manual*, p. 29 (interface PCIe Gen2, USB2 en debug)
- ThinkWiki, *Problem with unauthorized MiniPCI network card* (mécanique de la
  whitelist : sub-vendor PCI-ID et FRU) —
  `https://www.thinkwiki.org/wiki/Problem_with_unauthorized_MiniPCI_network_card`
- Lenovo, *ThinkPad P16 Gen 1 Hardware Maintenance Manual* —
  `https://download.lenovo.com/pccbbs/mobiles_pdf/p16_gen1_hmm_en.pdf`
  (Table 9 connecteurs carte mère, § 1180 lecteur de carte à puce)

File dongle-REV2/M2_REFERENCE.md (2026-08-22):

# M.2 Key B Integration -- Reference & Sources

Documentation de reference pour l'integration du dongle KaSe v2 dans un slot M.2 WWAN.

## Specification M.2

### Pinout Key B (Socket 2)

Source: [Congatec AN43](https://wiki.congatec.com/wiki/M.2_Pinout_Descriptions_and_Reference_Designs_(AN43))

| Pin | Signal | Pin | Signal |
|-----|---|-----|---|
| 1 | CONFIG_3 | 2 | 3.3V |
| 3 | GND | 4 | 3.3V |
| 5 | GND | 6 | ~FULL_CARD_POWER_OFF |
| 7 | **USB_D+** | 8 | ~W_DISABLE1 |
| 9 | **USB_D-** | 10 | GPIO_9/DAS/~DSS/~LED1 |
| 11 | GND | 12-19 | **(Key B notch)** |
| 20 | GPIO_5 | 21 | CONFIG_0 |
| 22 | GPIO_6 | 23 | GPIO_11 |
| 24 | DPR | 25 | GPIO_7 |
| 26 | GND | 27 | GPIO_10 |
| 28 | GPIO_8 | 29 | PERn1/USB3.0-Rx- |
| 30 | UIM-RESET | 31 | PERp1/USB3.0-Rx+ |
| 32 | UIM-DATA | 33 | GND |
| 34 | UIM-PWR | 35 | PETn1/USB3.0-Tx- |
| 36 | UIM-CLK | 37 | PETp1/USB3.0-Tx+ |
| 38 | DEVSLP | 39 | GND |
| 40 | GPIO_0/SMB_CLK | 41 | PERn0/SATA-B+ |
| 42 | GPIO_1/SMB_DATA | 43 | PERp0/SATA-B- |
| 44 | GPIO_2/~ALERT | 45 | GND |
| 46 | GPIO_3 | 47 | PETn0/SATA-A- |
| 48 | GPIO_4 | 49 | PETp0/SATA-A+ |
| 50 | ~PERST | 51 | GND |
| 52 | ~CLKREQ | 53 | REFCLKn |
| 54 | ~PEWAKE | 55 | REFCLKp |
| 56 | GND | 57 | NC |
| 58 | ANTCTL0 | 59 | NC |
| 60 | ANTCTL1 | 61 | ANTCTL2 |
| 62 | ANTCTL3 | 63 | COEX3 |
| 64 | COEX_TXD | 65 | COEX_RXD |
| 66 | SIM_DETECT | 67 | **~RESET** |
| 68 | CONFIG_1 | 69 | SUSCLK(32kHz) |
| 70 | GND | 71 | **3.3V** |
| 72 | GND | 73 | **3.3V** |
| 74 | CONFIG_2 | 75 | **3.3V** |

Note: le symbole KiCad `Connector:Bus_M.2_Socket_B` a pin 66=SIM_DETECT et pin 67=~RESET (pas l'inverse).

### Dimensions M.2

| Format | Largeur | Longueur | Usage typique |
|---|---|---|---|
| 2230 | 22mm | 30mm | WiFi, SSD |
| 2242 | 22mm | 42mm | SSD, WWAN |
| **3042** | **30mm** | **42mm** | **WWAN** |
| 2280 | 22mm | 80mm | SSD |

Epaisseur PCB: **0.8mm** (spec M.2 standard).

Le slot WWAN du Dell Latitude 5430 accepte du 3042 (module DW5820e = 30x42mm).

### CONFIG pins

Source: [Knightli M.2 Pinout Notes](https://www.knightli.com/en/2026/04/15/m2-pinout-descriptions/)

Les CONFIG pins sont "legacy" -- Linux n'utilise pas ces pins pour l'identification, il enumere le bus USB directement.
Source: [NVIDIA Forum](https://forums.developer.nvidia.com/t/m-2-key-b-config-x-signals-config-0-config-1-etc/335890)

Pour le dongle: tous les CONFIG en NC.

## CH334R -- Hub USB 2.0

### Datasheet

- [CH334/335 Datasheet V2.5 (PDF)](https://cdn-learn.adafruit.com/assets/assets/000/131/435/original/CH334DS1.PDF)
- [WCH Product Page](https://www.wch-ic.com/products/CH334.html)
- [CH334R sur JLCPCB (C4154405)](https://jlcpcb.com/partdetail/WCH_Jiangsu_Qin_Heng-CH334R/C4154405)

### Pinout CH334R (QSOP-16)

```
        CH334R (QSOP-16)
    +------------------------+
  1 | DM4-          XI    16 |
  2 | DM4+          XO    15 |
  3 | DM3-         GND    14 |
  4 | DM3+      VDD33    13 |
  5 | DM2-          5V    12 |
  6 | DM2+        DMU+   11 |
  7 | DM1-        DMU-   10 |
  8 | DM1+     RST/CDP    9 |
    +------------------------+
```

### Alimentation 3.3V (sans 5V)

La datasheet WCH confirme:

> "If there is an on-board 3.3V supply, both V5 and VDD33 of the HUB chip can be connected to the 3.3V supply. For industrial grade applications, it is recommended to connect both V5 and VDD33 to an external 3.3V power supply."

La variante CH334Q n'a pas de LDO interne ni de pin V5, preuve que le chip fonctionne en 3.3V natif.

Configuration dongle:
- Pin 12 (V5) -> 3.3V
- Pin 13 (VDD33) -> 3.3V + C 10uF

### Mode sans cristal

> "When the XO pin is suspended and the XI pin is connected to GND, the crystal-free mode is selected."

- Pin 16 (XI) -> GND
- Pin 15 (XO) -> NC

## Dell Latitude 5430 -- Slot WWAN

### Module d'origine

- Intel XMM 7360 (Dell DW5820e)
- LTE Cat9, 450Mbps DL
- Interface: **USB 2.0** (pas PCIe)
- Format: M.2 3042 Key B
- Source: [Intel XMM 7360 Specs](https://www.intel.com/content/www/us/en/products/sku/66649/intel-xmm-7360/specifications.html)

### Caracteristiques du slot

- USB 2.0 confirme (le DW5820e est un modem USB)
- 3.3V fourni par le slot
- PCIe present mais desactive dans le BIOS Dell (pas modifiable)
- Source: [Matt's Tech Pages - Dell M.2 WWAN](https://www.mattmillman.com/does-the-dell-latitude-m-2-wwan-socket-have-the-sata-interface-on-it/)

### BIOS Whitelist

- Dell est historiquement **permissif** sur le slot WWAN (pas de whitelist agressive comme Lenovo)
- Des utilisateurs ont installe des SSD dans le slot WWAN Dell sans probleme
- Risque residuel: le BIOS pourrait bloquer un VID/PID USB non reconnu
- Source: [Dell Community - SSD in WWAN slot](https://www.dell.com/community/en/conversations/latitude/info-installing-a-m2-ssd-in-the-wwan-slot-e5250-it-worked/647f85f2f4ccf8a8de4db82d)

### Test avant fabrication

Utiliser un adaptateur M.2 Key B -> USB en sens inverse pour verifier que le slot enumere un device USB custom.
- [Waveshare USB to M.2 B Key](https://www.waveshare.com/wiki/USB_TO_M.2_B_KEY)

## Footprints M.2 pour KiCad

### Utilises dans ce projet

- [timonsku/M.2-Card-Footprints](https://github.com/timonsku/M.2-Card-Footprints) -- Key B verifie sur PCB reel. Eagle + KiCad.
- [jmgao/kicad-ngff](https://github.com/jmgao/kicad-ngff) -- Footprints + symboles KiCad. Keys A, B, B+M, E, M.

### Autres librairies

- [realteck-ky/kicad-m2ngff](https://github.com/realteck-ky/kicad-m2ngff) -- Librairie KiCad M.2 NGFF.
- Symbole KiCad natif: `Connector:Bus_M.2_Socket_B`

## Projets similaires (detournement M.2)

- [timonsku/RP2040-M.2](https://github.com/timonsku/RP2040-M.2) -- RP2040 sur carte M.2 Key B, USB via slot WWAN. Le plus proche de notre projet.
- [enjoy-digital/litex_m2sdr](https://github.com/enjoy-digital/litex_m2sdr) -- FPGA SDR/RF sur M.2. GNU Radio compatible.
- [magic-blue-smoke/Dual-Edge-TPU-Adapter](https://github.com/magic-blue-smoke/Dual-Edge-TPU-Adapter) -- 2x Google Coral TPU sur un slot M.2.
- [themainframe/5g-m2-usb3-interface-pcb](https://github.com/themainframe/5g-m2-usb3-interface-pcb) -- Breakout USB3 M.2 Key B en KiCad.

## Articles de reference

- [M.2 For Hackers -- Connectors (Hackaday)](https://hackaday.com/2022/11/03/m-2-for-hackers-connectors/)
- [M.2 For Hackers -- Cards (Hackaday)](https://hackaday.com/2022/11/07/m-2-for-hackers-cards/)
- [M.2 For Hackers -- Expand Your Laptop (Hackaday)](https://hackaday.com/2022/10/27/m-2-for-hackers-expand-your-laptop/)
- [PCIe For Hackers -- An M.2 Card Journey (Hackaday)](https://hackaday.com/2023/07/20/pcie-for-hackers-an-m-2-card-journey/)
- [M.2 Connector Pinout (PinoutGuide)](https://pinoutguide.com/HD/M.2_NGFF_connector_pinout.shtml)
- [M.2 Pinout Generator (Nodeloop)](https://nodeloop.org/tools/m2-pinout-generator/)

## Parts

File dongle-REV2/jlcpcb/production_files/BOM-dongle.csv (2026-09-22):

Comment | Designator | Footprint | LCSC | Quantity
10uF | C12 | R_1206_3216Metric |  | 1
10uF | C9 | R_1206_3216Metric |  | 1
10k | R22 | R_0603_1608Metric |  | 1
100 | R16 | R_0603_1608Metric |  | 1
Bus_M.2_Socket_B | J2 | M.2_3042-xx-B |  | 1
220 | R1 | R_0603_1608Metric |  | 1
10uF | C4 | C_0603_1608Metric |  | 1
ESP32-S3-WROOM-1 | U7 | ESP32-S3-WROOM-1U |  | 1
100 | R4 | R_0603_1608Metric |  | 1
100 | R5 | R_0603_1608Metric |  | 1
100 | R8 | R_0603_1608Metric |  | 1
220 | R2 | R_0603_1608Metric |  | 1
100 | R3 | R_0603_1608Metric |  | 1
100nF | C5 | C_0603_1608Metric |  | 1
Conn_01x04_Pin | J1 | 1x04_SMD-2.54mm |  | 1
100nF | C1 | C_0603_1608Metric |  | 1
10k | R19 | R_0603_1608Metric |  | 1
10uF | C10 | R_1206_3216Metric |  | 1
10k | R18 | R_0603_1608Metric |  | 1
100nF | C7 | C_0603_1608Metric |  | 1
100 | R6 | R_0603_1608Metric |  | 1
100 | R7 | R_0603_1608Metric |  | 1
UMH3N | Q1 | SOT-363_SC-70-6 |  | 1
CH340C | U4 | SOIC-16_3.9x9.9mm_P1.27mm |  | 1
10k | R20 | R_0603_1608Metric |  | 1
100 | R17 | R_0603_1608Metric |  | 1
100 | R15 | R_0603_1608Metric |  | 1
10k | R23 | R_0603_1608Metric |  | 1
10k | R21 | R_0603_1608Metric |  | 1
10uF | C8 | R_1206_3216Metric |  | 1
10uF | C14 | R_1206_3216Metric |  | 1
NRF24L01_Breakout | U2 | NRF24L01 |  | 1
10uF | C13 | R_1206_3216Metric |  | 1
Jumper_2_Bridged | JP6 | Jumper |  | 1
NRF24L01_Breakout | U3 | NRF24L01 |  | 1
LD1117S33TR_SOT223 | U1 | SOT-223-3_TabPin2 |  | 1
Jumper_2_Bridged | JP4 | Jumper |  | 1
Jumper_2_Bridged | JP5 | Jumper |  | 1
Jumper_2_Bridged | JP2 | Jumper |  | 1
10uF | C11 | R_1206_3216Metric |  | 1
SS14 | D1 | D_SMA |  | 1
Jumper_2_Bridged | JP3 | Jumper |  | 1

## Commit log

2026-08-22 Depot initial : les trois variantes de dongle USB
    Extrait de harrael/SpLiT_KaSe, ou le dongle cohabitait avec le clavier et
    dependait de bibliotheques d'empreintes referencees en chemins absolus
    (/home/mae/Documents/PCB-esp/...), ce qui rendait le projet non clonable.
    - dongle-s3 : ESP32-S3-WROOM-1 + CH334R + CH340C + 2x NRF24L01, M.2 Key B 3042
    (version fabriquee, gerbers du 27/05/2026)
    - dongle-p4 : variante ESP32-P4 QFN104, en cours
    - dongle-ext : version a connecteurs 2.54, sans bord de carte M.2
    Les empreintes maison sont regroupees dans libs/ et referencees en
    ${KIPRJMOD}/../libs/... par chaque fp-lib-table. Verifie : les trois projets
    resolvent toutes leurs biblioth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
    [dongle-B_Cu.gbr, dongle-B_Mask.gbr, dongle-B_Paste.gbr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]
2026-08-22 README : rendus de la carte V1.0
    Ajoute les deux rendus fournis par Mae (dessus / dessous) et precise que la
    serie fabriquee est la V1.0 : la source de dongle-s3 est passee en V1.1
    depuis (R9 supprimee, C8 a C12 ajoutes), les gerbers du 27/05 ne
    correspondent donc plus au PCB courant.
    Claude-Session: https://claude.ai/code/session_01Cs6iS4p36JwXPGk94TNDjC
2026-08-22 README bilingue anglais/francais, et dongle-s3 note comme en service
    Version anglaise en premier, version francaise a la suite.
    Precise aussi que la V1.0 de dongle-s3 n'est pas seulement fabriquee : elle
    tourne dans le slot M.2 WWAN du portable depuis plusieurs mois et fonctionne
    en clavier USB HID.
    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
2026-08-22 README : le dongle sert Niphargus et Conchodytes, pas le KaSe
    Le recepteur est la cible commune du clavier split Niphargus et de la souris
    Conchodytes (a venir) — les deux depots le designent d'ailleurs comme "the
    same KaSe dongle". L'intro parlait du clavier KaSe, ce qui n'est plus la bonne
    cible.
    Precise aussi l'affectation radio : une NRF par moitie de Niphargus, chaque
    moitie etant autonome (ESP32-S3 + nRF24L01+ + 16340) et emettant sur son
    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
2026-09-22 docs: le slot WWAN du ThinkPad P16 n'alimente pas la V1.0 (pins CONFIG flottantes)
    Claude-Session: https://claude.ai/code/session_01BwrB7Wni62hiL8wx3engVE
2026-09-22 REV2 : hub supprimé, pins CONFIG déclarées, alimentation de banc
    `dongle-s3` devient `dongle-REV1`, la carte V1.0 actuellement en service.
    `dongle-REV2` en part pour répondre au slot WWAN du ThinkPad P16 Gen 1 :
    la V1.0 laisse ses quatre pins CONFIG flottantes, l'hôte lit « pas de
    carte » et n'alimente jamais le slot.
    - JP2-JP5 : CONFIG_0..3 vers GND, ouverts par défaut, pour déclarer un
    code à la goutte de soudure et les balayer selon l'hôte
    - hub CH334R (U6) supprimé, avec C6 et J3 ; l'ESP32-S3 attaque
    directement les pins 7/9 du M.2, un seul périphérique USB dont le
    firmware maîtrise le VID/PID
    - CH340C déplacé sur J1, en port de programmation de banc
    - U1 (LD1117S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
    [BOM-dongle.csv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]
2026-09-22 docs : retours publics sur les cartes USB en slot M.2, et état de REV2
    Le contrôle 1802 vérifie le sub-vendor PCI-ID plus un numéro FRU Lenovo.
    Une carte purement USB n'a pas de PCI-ID : ce verrou n'est probablement
    pas celui qui bloque, contrairement à ce qui était écrit ici. Le vrai
    obstacle reste l'alimentation du slot, et il s'est durci — la Fibocom
    L860-GL que le P16 accepte est PCIe Gen2, l'USB2 n'y servant qu'au debug.
    Ajouts :
    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
2026-09-22 README : brochage RESET# corrigé, et un README par variante
    R22 n'est pas un pull-up. Il relie `RESET#` (pin 67 du M.2) au nœud `EN`
    de l'ESP32-S3, qui porte par ailleurs R19 en pull-up et C7 de 100 nF vers
    la masse. L'hôte peut donc réinitialiser le module par la pin 67 : un
    slot qui maintiendrait `RESET#` bas le garderait en reset même alimenté.
    Seuls `W_DISABLE1#` et `FULL_CARD_POWER_OFF#` ont de vrais pull-ups.
    Les trois README de variante étaient la même copie d'un vieux fichier
    « KaSe v2 », y compris dans dongle-ext qui n'a pas de connecteur M.2.
    Erreurs qui disparaissent au passage : ESP32-S3-WROOM-2 au lieu de -1,
    « UMH3N x2 » pour un seul boîtier à deux unités, 22 x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
2026-10-13 P16 Gen 1 : le slot WWAN n'alimente sur aucun code, enquête close
    Dix des seize combinaisons CONFIG essayées sur le ThinkPad P16 Gen 1, dont
    les six définies par la spec. Résultat : le rail 3,3 V du slot n'est jamais
    monté, et les trois codes WWAN haltent la machine en
    1802: Unauthorized network card is plugged in
    System is halted
    Le mécanisme est donc : lire CONFIG -> autoriser -> alimenter, et il ne
    franchit jamais la deuxième étape. Un code non-WWAN est ignoré en silence et
    sans courant ; un code WWAN engage le contrôle, échoue, et halte.
    Ce qui confirme l'hypothèse de départ — l'hôte lit bien les quatre broches
    avant de décider — et invalide ce que ce docume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
2026-10-14 P16 Gen 1 : le port USB du slot est désactivé lui aussi, chapitre clos
    Second essai, le 14/10/2026. Le BIOS refusant d'alimenter, restait
    l'hypothèse que les données soient quand même câblées — D+/D- va en général
    du contrôleur hôte au connecteur en direct, et c'est le rail 3,3 V qu'un load
    switch coupe, pas le lien USB.
    Jumpers CONFIG tous ouverts, donc 1111, donc aucun 1802 et un démarrage
    normal. Machine démarrée, 3,3 V injectés sur les embases 2 mm des nRF24,
    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
2026-10-14 docs : M2_REFERENCE fusionné en un seul fichier, brochage corrigé
    Les trois M2_REFERENCE.md étaient des copies identiques — une par variante,
    y compris dans dongle-ext qui n'a pas de connecteur M.2 — et portaient encore
    le nom « KaSe v2 ». Fusionnés en docs/m2-key-b.md.
    Deux corrections de fond au passage.
    Le tableau de brochage était faux à partir de la pin 68 : chaque nom y était
    attribué à la broche voisine, d'où un « pin 75 = 3,3 V » alors que la 75 porte
    CONFIG_2, et un « 71/73 = 3,3 V » alors que ce sont des masses. C'est de là
    que venait l'erreur retrouvée dans les trois README de variante. La table est
    régénérée depuis le symbole Connector:Bus_M.2_Socket_B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
